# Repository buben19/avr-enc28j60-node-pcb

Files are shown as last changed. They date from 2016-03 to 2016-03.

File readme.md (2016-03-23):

# IoT node pcb

PCB design for AVR ENC28J60 IoT node board. This repository contains only board
design files, design files for 3D printable case are stored in different repository.

## Features

 - AVR [ATmega328P](http://www.atmel.com/devices/atmega328p.aspx) main microcontroller ([Arduino Pro Mini](https://www.arduino.cc/en/Main/ArduinoBoardProMini)).
 - Ethernet connection with [ENC28J60](http://www.microchip.com/wwwproducts/en/en022889) chip.
 - ENC28J60 powered by mini DC-DC power supply module ([LM2596](http://www.ti.com/lit/ds/symlink/lm2596.pdf) chip).
 - Two RJ-11 connectors for sensors.
 - Powered using  5.5 mm power socket. Central positive,  7-12V.
 - Modular design.
 - Notification LED.
 - Intended  to be manufactured by [dirtypcbs.com](http://dirtypcbs.com/).
 - Optional on board 5V voltage stabilizer. You don't need to rely to voltage stabilizer on Arduino module.

## Images

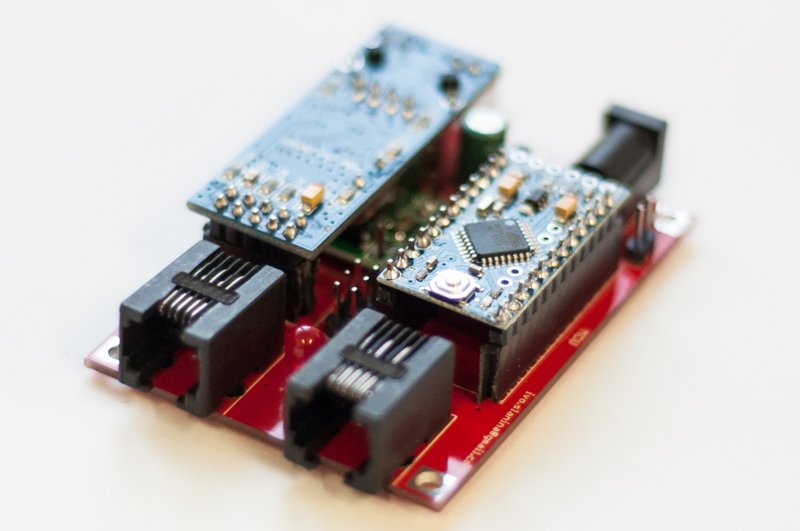
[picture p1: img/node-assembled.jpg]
Assembled node


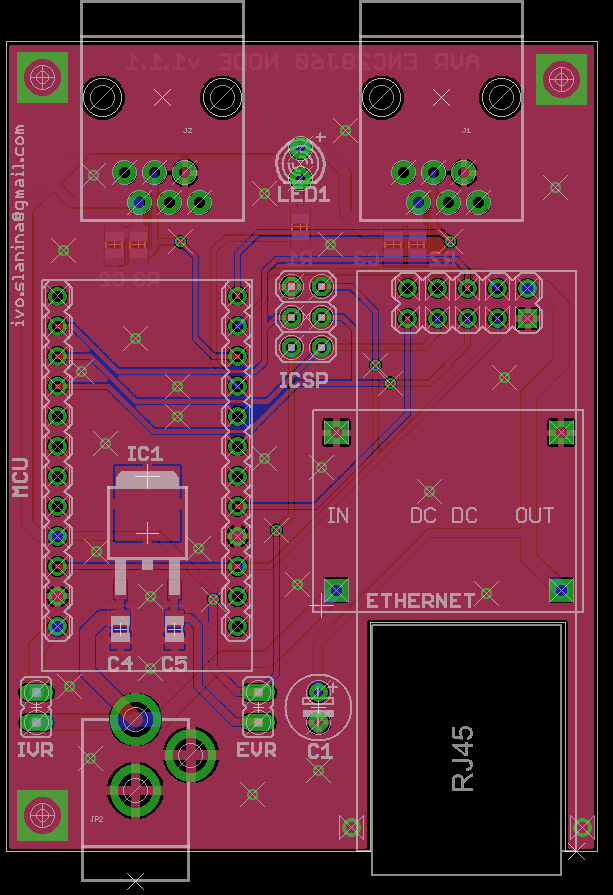
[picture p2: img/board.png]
Board design Node board design


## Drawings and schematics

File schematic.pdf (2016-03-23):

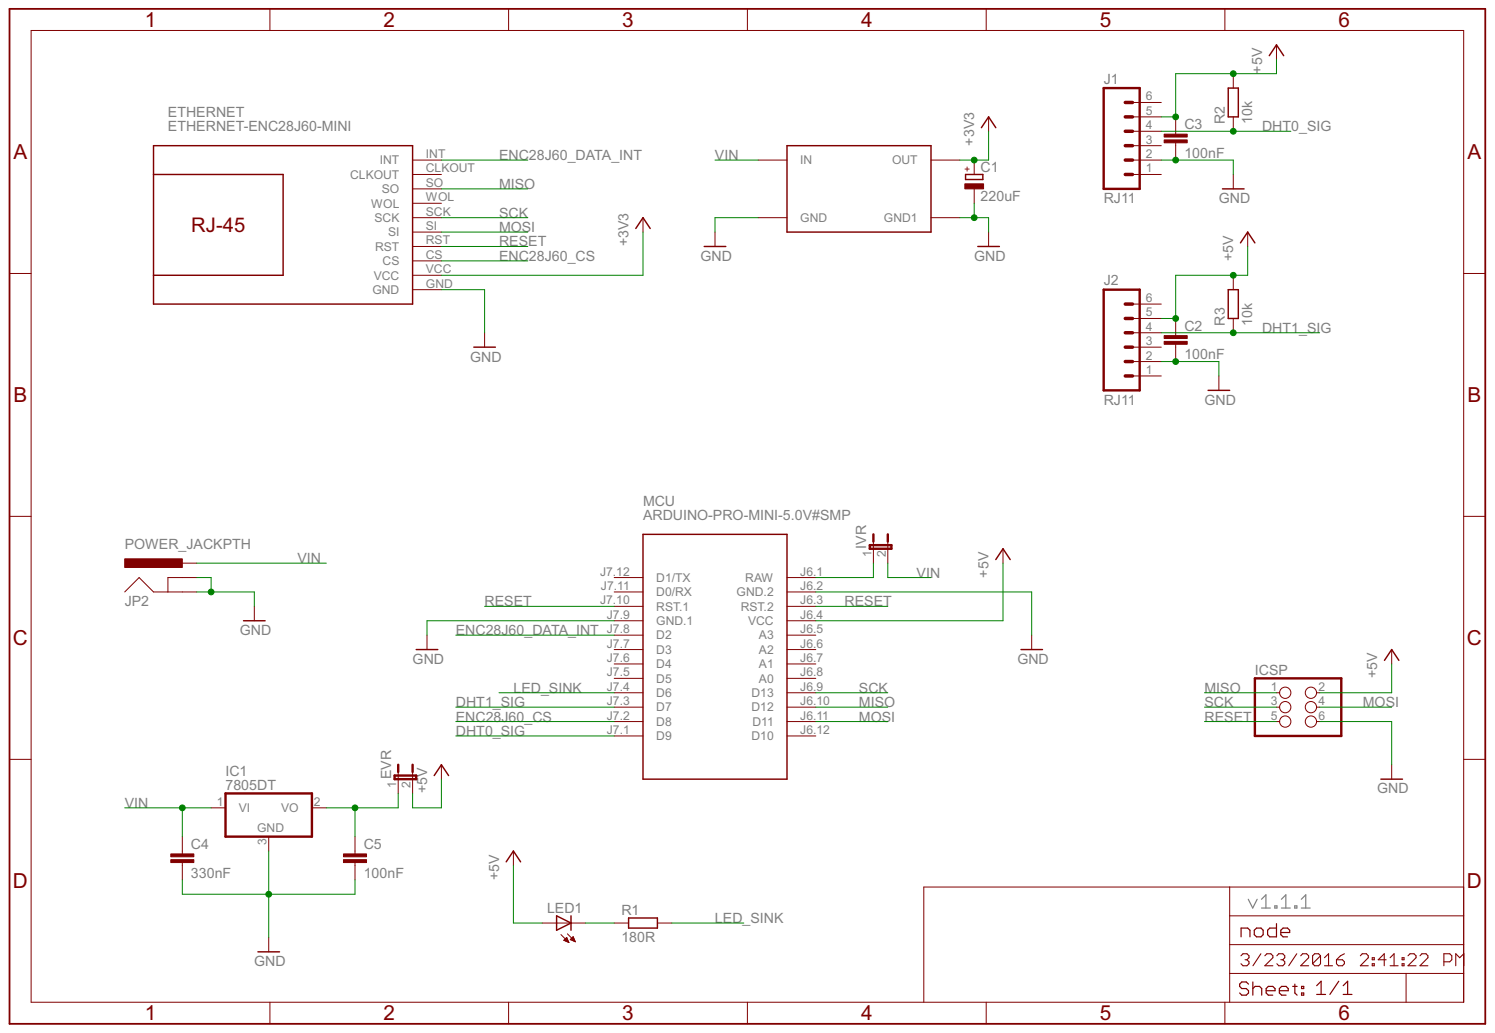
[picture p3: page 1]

MCU
ARDUINO-PRO-MINI-5.0V#SMP

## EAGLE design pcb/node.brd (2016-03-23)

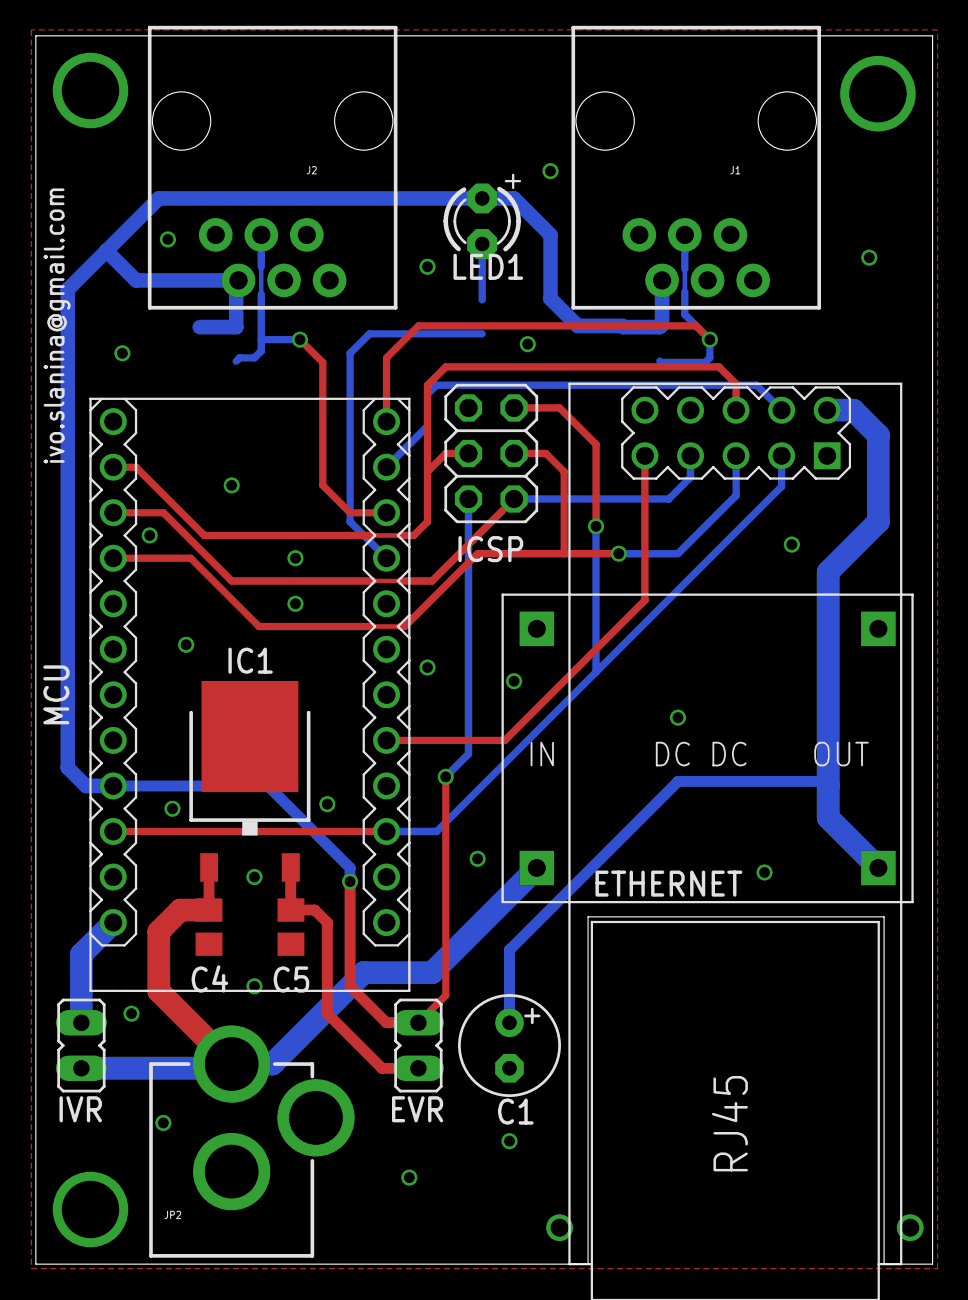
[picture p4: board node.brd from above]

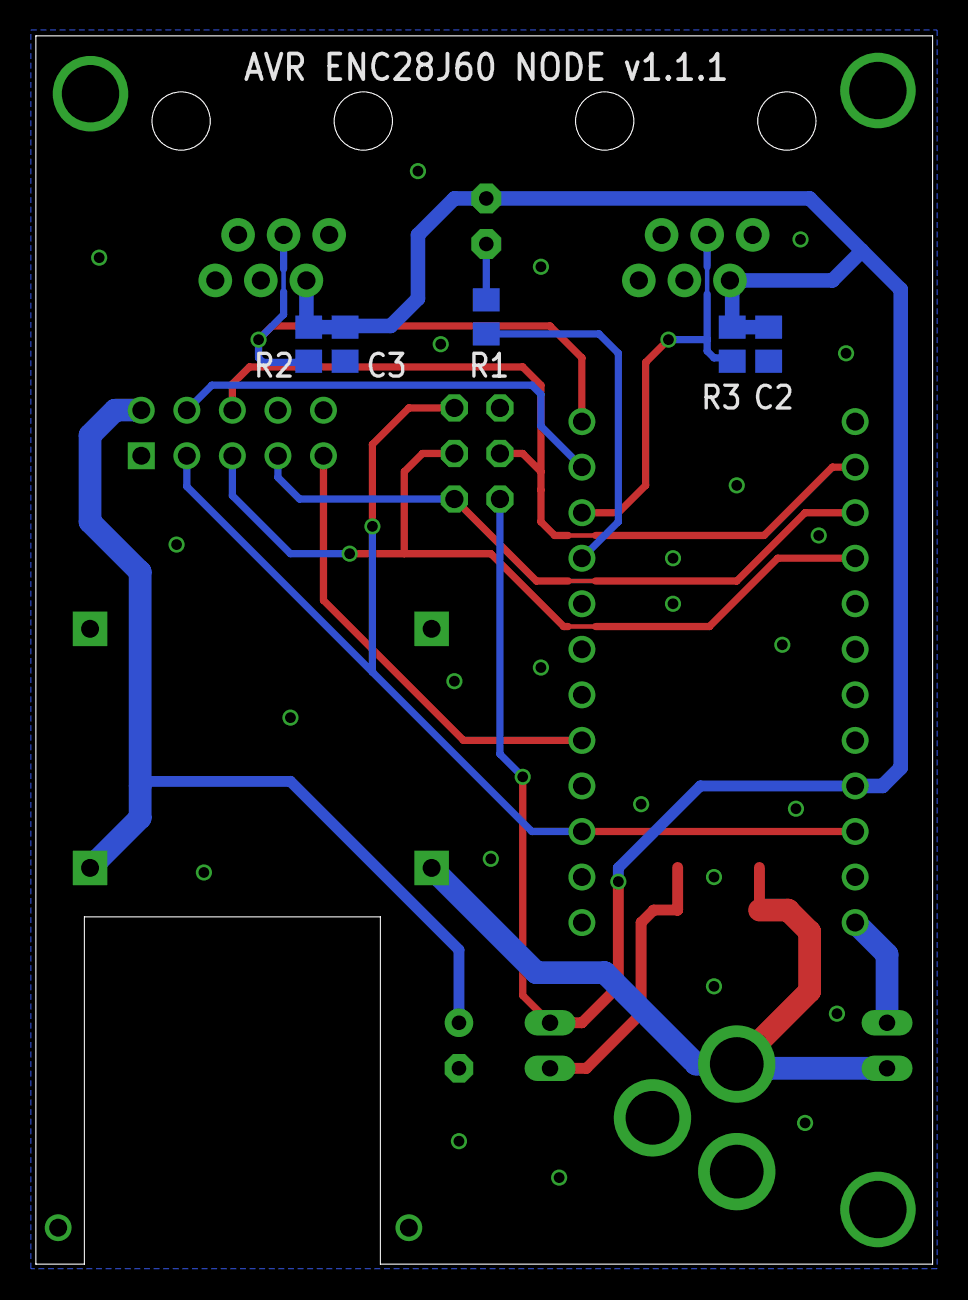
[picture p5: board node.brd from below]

Board: 2 copper layers, 50.0 x 68.5 mm, 19 parts (5 on the bottom side), 16 nets.

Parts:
C1: 220uF; E2,5-6
C2, C3, C5: 100nF; C0805
C4: 330nF; C0805
ETHERNET: ETHERNET-ENC28J60-MINI
EVR: JP1
IC1: 7805DT; TO252
ICSP: 2X03
IVR: JP1
J1, J2: RJ11; RJ11-6
JP2: POWER_JACKPTH; POWER_JACK_PTH
LED1: LED3MM
MCU: ARDUINO-PRO-MINI-5.0V#SMP; ARDUINO-PRO-MINI#SMP
R1: 180R; R0805
R2, R3: 10k; R0805
U$2: DC-DC-SMALL; DC-DC

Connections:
+3V3: C1.+, ETHERNET.VCC, U$2.P$2
+5V: C2.1, C3.1, EVR.2, ICSP.2, J1.5, J2.5, LED1.A, MCU.J6.4, R2.2, R3.2
DHT0_SIG: J1.4, MCU.J7.1, R2.1
DHT1_SIG: J2.4, MCU.J7.3, R3.1
ENC28J60_CS: ETHERNET.CS, MCU.J7.2
ENC28J60_DATA_INT: ETHERNET.INT, MCU.J7.8
GND: C1.-, C2.2, C3.2, C4.2, C5.2, ETHERNET.GND, IC1.3, ICSP.6, J1.2, J2.2, JP2.GND, JP2.GNDBREAK, MCU.J6.2, MCU.J7.9, U$2.P$3, U$2.P$4
LED_SINK: MCU.J7.4, R1.2
MISO: ETHERNET.SO, ICSP.1, MCU.J6.10
MOSI: ETHERNET.SI, ICSP.4, MCU.J6.11
unnamed: LED1.K, R1.1
unnamed: IVR.1, MCU.J6.1
unnamed: C5.1, EVR.1, IC1.2
RESET: ETHERNET.RST, ICSP.5, MCU.J6.3, MCU.J7.10
SCK: ETHERNET.SCK, ICSP.3, MCU.J6.9
VIN: C4.1, IC1.1, IVR.2, JP2.PWR, U$2.P$1

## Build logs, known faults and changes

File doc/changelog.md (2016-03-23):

# AVR ENC28J60 Node changelog

## v1.0

 - Initial version.
 - Single layer board design.
 - Intended to be manufactured by [plosnaky.cz](http://www.plosnaky.cz/).
 - Two RJ-11 connectors for DHT-22 sensor.
 - ENC28J60 communication module.

## v1.1

 - Changed board design to two layers.
 - Intended  to be manufactured by [dirtypcbs.com](http://dirtypcbs.com/)
 - Added external 5V voltage regulator ([LM78M05](https://www.fairchildsemi.com/datasheets/MC/MC78M05.pdf)).
 - Added jumper for enabling external voltage regulator (EVR).
 - Added jumper for enabling internal voltage regulator (IVR).
 - Added 10k pull-up resistors to DHT-22 data line.
 - Replaced notification LED current limiting resistor to SMD variant.

## v1.1.1

 - Fixed version number in schematic file.
 - Changed board label to "AVR ENC28J60 NODE".
 - Updated some part names.

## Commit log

2015-11-24 case: first commit
    [bottom.ipt, case.iam, node.brd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]
2015-11-24 Fixed case top part.
    [case.iam, top.ipt]
2016-01-11 New two layer board version (dirtypcbs.com).
    [node.brd, node.sch]
2016-01-12 Minor fixes (verion number, signature, added some vias).
    [node.brd]
2016-01-12 Changed arduino footprint. Removed drills for unnecessary pins.
    [node.brd, node.sch]
2016-01-15 Final release.
    [node.brd, node.sch]
2016-02-06 Added STL files.
    [bottom.stl, top.stl]
2016-02-18 Removed case.
    [bottom.ipt, bottom.stl, case.iam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]
2016-02-22 Some formal changes.
    [node.brd, node.sch]
2016-02-22 Changed voltage regulator input capacitor value.
    [node.brd, node.sch]
2016-02-22 Changed notification LED current limiting resistor value.
    [node.brd, node.sch]
2016-03-23 Added board image and schematic pdf file.
2016-03-23 Added photo of assembled node.
2016-03-23 Fixed some part names. Changed board label.
    [node.brd, node.sch]
2016-03-23 Updated pdf schematic and board desig image.

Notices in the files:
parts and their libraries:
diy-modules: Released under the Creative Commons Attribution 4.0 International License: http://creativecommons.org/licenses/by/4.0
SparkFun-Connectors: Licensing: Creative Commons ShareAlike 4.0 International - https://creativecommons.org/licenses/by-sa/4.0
